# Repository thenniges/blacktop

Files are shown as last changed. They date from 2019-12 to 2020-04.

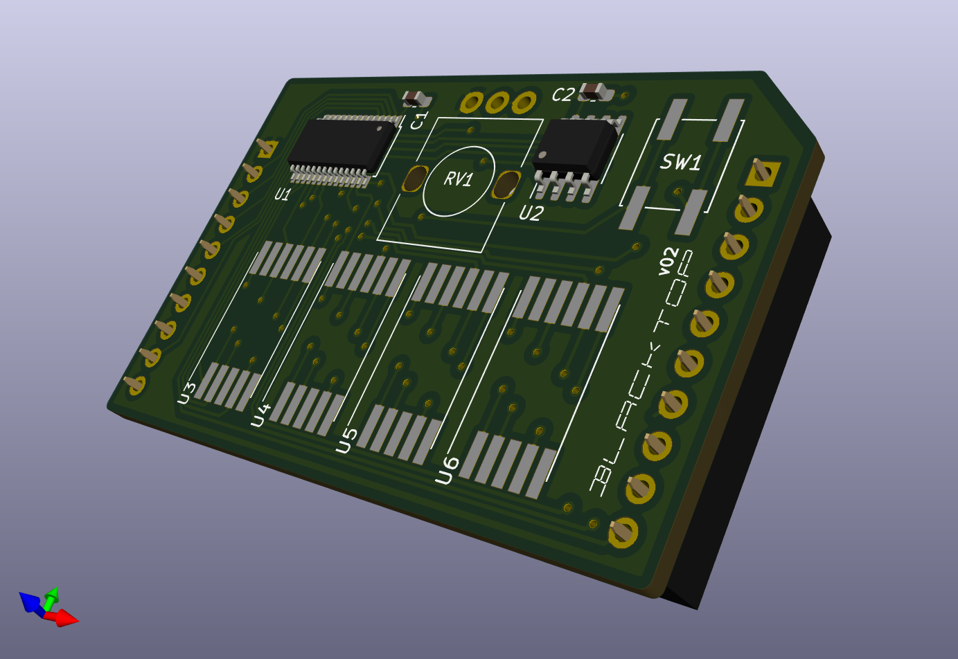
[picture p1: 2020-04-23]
hw/v02/blacktop02.png

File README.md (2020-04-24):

# Blacktop
When cloning this project you need to make some additional git commands to get the unity unit test framework and cmock mock framework

cd blacktop

git submodule init

git submodule update

# Test scripts

There is a test script in the blacktop directory that will run unit tests every time that you save any of the source code. It will run all the unit tests for all subdirectories.

In order to use it you need to install a python tool called when-changed. The command is:

pip install when-changed

Run it in the blacktop directory using the following command:

./watchtests.sh

There is also a system test script in the test folder that can be ran using the following command:

./runtest.sh

# Directories

license: contains the relevant license files for this project

standards: contains the coding standards that should be followed for this project

src: contains the source code and appropriate tests for this project

doc: contains the documentation for this project

spikes: contains spikes that have been done to understand how this project will work

hw: contails kicad files defining the hardware design

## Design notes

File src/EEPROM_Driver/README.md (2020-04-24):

This code uses the Serial Peripheral Interface to allow users to initialize, erase, read, and write the EEPROM memory chip.

eeprom.c and eeprom.h contain the interface for the user to be able to interact with the EEPROM without any knowledge of SPI.
It allows them to be able to easily read and write data to the EEPROM off-chip memory device. The functions are explained briefly in eeprom.h

hardwareDriver.c and hardwareDriver.h allow the eeprom driver to interact with the hardware. None of these functions are intended to be used by the user. They are called appropriately from eeprom.c and eeprom.h 

main.c is used as a system test to ensure that the code is working on your board.

The make file is set up to run the code with main.c as the source file and eeprom.c and hardwareDriver.c as additional files. You can take eeprom.c, eeprom.h, hardwareDriver.c, and hardwareDriver.h and use them with other code. You can also take the makefile and change the source line and add any additional files.

to build the code:
$ make

to remove the binaries:
$ make clean

to flash the code:
$ make flash

to erasse the micro:
$ make erase

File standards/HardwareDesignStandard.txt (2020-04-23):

Use KiCAD 5 for board design.

Use the default KiCAD design rules for feature size and separation.

Instructions for board design in KiCAD 5 are found in Contextual Electronics' "Getting To Blinky 5.0" on YouTube:
https://www.youtube.com/playlist?list=PLy2022BX6EspFAKBCgRuEuzapuz_4aJCn

Schematics must pass KiCAD's Electric Rules Check (ERC) with no errors or warnings.

Layouts must pass KiCAD's Design Rules Check (DRC) with no errors or warnings.

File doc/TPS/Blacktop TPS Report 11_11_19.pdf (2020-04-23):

CS 4900
Project: Blacktop
TPS Report
11/11//2019
Team: | Skyler Sheler | skyler.j.sheler@wmich.edu | (616) 438-3527
| Erron Johnson | erron.d.johnson@wmich.edu | (269) 547-8933
| Allin Kahrl | f.allin.kahrl@wmich.edu | (207) 522-4859
| Tyler Henniges | tyler.m.henniges@wmich.edu | (269) 330-4229
Client: | WMU Computer Club colin.c.maccreery@wmich.edu | (269) 276-3106
Contact: | Colin MacCreery | colin.c.maccreery@wmich.edu | (269) 276-3106
Project Lead Allin Kahrl | f.allin.kahrl@wmich.edu | (207) 522-4859
Task | Who will complete | Time | Risk 1-10 | % complete | Actual time | review
T1 | SS | 1 hour | 1 | 100% | 1 hour | AK TH EJ
T2 | SS AK TH EJ | 1 hour or less | 1 | 75% | TBD | TBD
T3 | SS AK TH EJ | 1 hour | 1 | 100% | 1 hour | AK SS TH EJ
T4 | SS AK TH EJ | 10 hours | 4 | 30% | TBD | TBD
T5 | SS AK TH EJ | 10 hours | 7 | 20% | TBD | TBD
T6 | SS AK TH EJ | 10 hours | 8 | 20% | TBD | TBD

T1: Write the requested deliverables for the week
Write the TPS Report and Stories for the week
T2: Install the toolchain for the MSP 430.
The toolchain necessary to use the board will have to be installed before any circuit prototypes can be tested.
T3: Decide on a licence for the project.

Licencing has yet to be decided upon. This will have to be discussed with the client at our next meeting.

T4: Begin breadboarding a prototype board.
The components will have to be socketed into a breadboard and tested for full functionality. This is currently the largest portion of the project to overcome and time specifications will have to be further analyzed.
T5: Develope drivers using SPI to interface with the on-board EEPROM
Drivers must be developed using a serial peripheral interface to transfer data from the main board to the on-board EEPROM
T6: Develop the CAD files for the production circuit board
The circuit board must be designed via KiCAD before a prototype board can be ordered

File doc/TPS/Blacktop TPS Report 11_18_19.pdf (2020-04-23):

CS 4900
Project: Blacktop
TPS Report
11/18//2019
Team: | Skyler Sheler | skyler.j.sheler@wmich.edu | (616) 438-3527
| Erron Johnson | erron.d.johnson@wmich.edu | (269) 547-8933
| Allin Kahrl | f.allin.kahrl@wmich.edu | (207) 522-4859
| Tyler Henniges | tyler.m.henniges@wmich.edu | (269) 330-4229
Client: | WMU Computer Club colin.c.maccreery@wmich.edu | (269) 276-3106
Contact: | Colin MacCreery | colin.c.maccreery@wmich.edu | (269) 276-3106
Project Lead Allin Kahrl | f.allin.kahrl@wmich.edu | (207) 522-4859
Task | Who will complete | Time | Risk 1-10 | % complete | Actual time | review
T1 | SS | 1 hour | 1 | 100% | 1 hour | AK TH EJ
T2 | SS AK TH EJ | 1 hour or less | 1 | 100% | 1 hour | AK SS TH
T3 | SS AK TH EJ | 5 hours | 3 | 20% | TBD | TBD
T4 | SS AK TH EJ | 10 hours | 3 | 50% | TBD | TBD
T5 | SS AK TH EJ | 10 hours | 6 | 30% | TBD | TBD
T6 | SS AK TH EJ | 10 hours | 6 | 30% | TBD | TBD

T1: Write the requested deliverables for the week
Write the TPS Report and Stories for the week
T2: Install the toolchain for the MSP 430.

The toolchain necessary to use the board will have to be installed before any circuit prototypes can be tested.
T3: Test the board to see if it can handle all of the peripherals being turned on at once
The maximum current load of the board must be determined, and if turning on all peripherals exceeds that load a failsafe must be developed to prevent the board from breaking.
T4: Begin breadboarding a prototype board.
The components will have to be socketed into a breadboard and tested for full functionality. This is currently the largest portion of the project to overcome and time specifications will have to be further analyzed.
T5: Develop drivers using SPI to interface with the on-board EEPROM
Drivers must be developed using a serial peripheral interface to transfer data from the main board to the on-board EEPROM
T6: Develop the CAD files for the production circuit board
The circuit board must be designed via KiCAD before a prototype board can be ordered

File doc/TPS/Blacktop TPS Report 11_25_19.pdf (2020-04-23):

CS 4900
Project: Blacktop
TPS Report
11/25//2019
Team: | Skyler Sheler | skyler.j.sheler@wmich.edu | (616) 438-3527
| Erron Johnson | erron.d.johnson@wmich.edu | (269) 547-8933
| Allin Kahrl | f.allin.kahrl@wmich.edu | (207) 522-4859
| Tyler Henniges | tyler.m.henniges@wmich.edu | (269) 330-4229
Client: | WMU Computer Club colin.c.maccreery@wmich.edu | (269) 276-3106
Contact: | Colin MacCreery | colin.c.maccreery@wmich.edu | (269) 276-3106
Project Lead Allin Kahrl | f.allin.kahrl@wmich.edu | (207) 522-4859
Task | Who will complete | Time | Risk 1-10 | % complete | Actual time | review
T1 | SS | 1 hour | 1 | 100% | 1 hour | AK TH EJ
T2 | SS | 1 hour | 1 | 100% | 1 hour | AK TH EJ
T3 | SS AK TH EJ | 5 hours | 3 | 40% | TBD | TBD
T4 | SS AK TH EJ | 10 hours | 3 | 60% | TBD | TBD
T5 | SS AK TH EJ | 10 hours | 6 | 30% | TBD | TBD
T6 | SS AK TH EJ | 10 hours | 5 | 40% | TBD | TBD
T7 | SS | 3 hours | 1 | 100% | 3 hours | AK
T8 | TH | 1 hour | 1 | 100% | 1 hour | SS AK EJ

T1: Write the requested deliverables for the week
Write the TPS Report and Stories for the week
T2: Test a program on the TSOP MSP-430 chip

The chips soldered to breakout boards must be tested and flashable using the methods used by students in CS2230. Test code was provided to make sure the program operates and performs to the specified standards. Three prototype MSP-430 chips were connected to the programmer via breadboard and tested using a text to ascii code conversion program used in CS2230. The program ran successfully with no errors. The boards were also flashed with a .elf file that causes the on-board rgb to pulse slowly. The program flashed and ran with no errors.
T3: Test the board to see if it can handle all of the peripherals being turned on at once
The maximum current load of the board must be determined, and if turning on all peripherals exceeds that load a failsafe must be developed to prevent the board from breaking.
T4: Finish breadboarding a prototype board.
The components will have to be socketed into a breadboard and tested for full functionality. This is currently the largest portion of the project to overcome and time specifications will have to be further analyzed.
T5: Develop drivers using SPI to interface with the on-board EEPROM
Drivers must be developed using a serial peripheral interface to transfer data from the main board to the on-board EEPROM
T6: Develop the CAD files for the production circuit board
The circuit board must be designed via KiCAD before a prototype board can be ordered T7: Solder together more TSOP MSP-430 programmable chips
Two more TSOP packages were soldered together in case any hardware errors occurred from hand soldering the chips to their respective breakout boards. Allin Kahrl experienced difficulties in getting the package to flash properly so additional boards were made and tested for him to use while the board he used was repaired,
T8: Create a gantt chart to simplify scheduling.
A gantt chart was created to promote steady workflow and establish a well defined timeline for the project.

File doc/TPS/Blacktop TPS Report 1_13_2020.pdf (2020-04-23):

CS 4910
Project: Blacktop
TPS Report
1/13/2020
Team: | Skyler Sheler | skyler.j.sheler@wmich.edu | (616) 438-3527
| Erron Johnson | erron.d.johnson@wmich.edu | (269) 547-8933
| Allin Kahrl | f.allin.kahrl@wmich.edu | (207) 522-4859
| Tyler Henniges | tyler.m.henniges@wmich.edu | (269) 330-4229
Client: | WMU Computer Club colin.c.maccreery@wmich.edu | (269) 276-3106
Contact: | Colin MacCreery | colin.c.maccreery@wmich.edu | (269) 276-3106
Project Lead Allin Kahrl | f.allin.kahrl@wmich.edu | (207) 522-4859
Task | Who will complete | Time | Risk 1-10 | % complete | Actual time | review
T1 | SS | 1 hour | 1 | 100% | 1 hour | AK TH EJ
T2 | SS AK TH EJ | 5 hours | 3 | 50% | TBD | TBD
T3 | SS AK TH EJ | 10 hours | 3 | 80% | TBD | TBD
T4 | SS AK TH EJ | 10 hours | 6 | 70% | TBD | TBD
T5 | SS AK TH EJ | 10 hours | 5 | 50% | TBD | TBD
T6 | AK TH | 5 hours | 1 | 100% | 5 hours | TBD
T1: Write the requested deliverables for the week
Write the TPS Report and Stories for the week
T2: Test the board to see if it can handle all of the peripherals being turned on at once
The maximum current load of the board must be determined, and if turning on all peripherals exceeds that load a failsafe must be developed to prevent the board from breaking.
T3: Finish breadboarding a prototype board.

The components will have to be socketed into a breadboard and tested for full functionality. This is currently the largest portion of the project to overcome and time specifications will have to be further analyzed.
T4: Develop drivers using SPI to interface with the on-board EEPROM
Drivers must be developed using a serial peripheral interface to transfer data from the main board to the on-board EEPROM
T5: Develop the CAD files for the production circuit board
The circuit board must be designed via KiCAD before a prototype board can be ordered T6: Develop a testing plan for the project.
A testing plan for accessibility, user, unit, and system testing must be developed to confirm the projects completeness.

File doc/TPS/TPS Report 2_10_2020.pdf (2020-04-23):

CS 4910
Project: Blacktop
TPS Report
2/10/2020
Team: | Skyler Sheler | skyler.j.sheler@wmich.edu | (616) 438-3527
| Erron Johnson | erron.d.johnson@wmich.edu | (269) 547-8933
| Allin Kahrl | f.allin.kahrl@wmich.edu | (207) 522-4859
| Tyler Henniges | tyler.m.henniges@wmich.edu | (269) 330-4229
Client: | WMU Computer Club colin.c.maccreery@wmich.edu | (269) 276-3106
Contact: | Colin MacCreery | colin.c.maccreery@wmich.edu | (269) 276-3106
Project Lead Allin Kahrl | f.allin.kahrl@wmich.edu | (207) 522-4859
Task | Who will complete | Time | Risk 1-10 | % complete | Actual time | review
T1 | SS | 1 hour | 1 | 100% | 1 hour | AK TH EJ
T2 | SS AK TH EJ | 5 hours | 3 | 100% | TBD | TBD
T3 | SS AK TH EJ | 10 hours | 3 | 80% | TBD | TBD
T4 | SS AK TH EJ | 10 hours | 6 | 75% | TBD | TBD
T5 | AK | 5 hours | 4 | 25% | TBD | TBD
T6 | SS | 10 hours | 5 | 0% | TBD | TBD
T7 | SS TH | 1 hour | 1 | 100% | 1 hour | AK EJ
T8 | TH | 1 hour | 1 | 100% | 1 hour | SS AK EJ
T9 | SS AK | 5 hours | 1 | 50% | TBD | TBD
T10 | TH | 1 hour | 1 | 100% | 1 hour | SS AK EJ
T11 | AK | 1 hour | 1 | 100% | 1 hour | SS TH EJ

T1: Write the requested deliverables for the week
Write the TPS Report and Stories for the week
T2: Test the board to see if it can handle all of the peripherals being turned on at once
The maximum current load of the board must be determined, and if turning on all peripherals exceeds that load a failsafe must be developed to prevent the board from breaking.
T3: Finish breadboarding a prototype board.
The components will have to be socketed into a breadboard and tested for full functionality. This is currently the largest portion of the project to overcome and time specifications will have to be further analyzed.
T4: Develop drivers using SPI to interface with the on-board EEPROM
Drivers must be developed using a serial peripheral interface to transfer data from the main board to the on-board EEPROM
T5: Create revision 3 boards after testing the revision 1 and 2 boards.
T6: Begin Soldering the revision 1 and 2 boards.
T7: Begin research into circuit python for the test jig and its development.
T8: Rework the gantt chart to reflect the current list of completed tasks.
T9: Refine the preliminary powerpoint presentation to reflect desired improvements listed by the class
T10: Decide on an array of possible circuit boards to use for the test jig
T11: Inspect the printed circuit boards that have been ordered and decide on which one to use for first and second stage prototyping

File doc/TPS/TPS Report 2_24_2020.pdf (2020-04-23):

CS 4910
Project: Blacktop
TPS Report
2/24/2020
Team: | Skyler Sheler | skyler.j.sheler@wmich.edu | (616) 438-3527
| Erron Johnson | erron.d.johnson@wmich.edu | (269) 547-8933
| Allin Kahrl | f.allin.kahrl@wmich.edu | (207) 522-4859
| Tyler Henniges | tyler.m.henniges@wmich.edu | (269) 330-4229
Client: | WMU Computer Club colin.c.maccreery@wmich.edu | (269) 276-3106
Contact: | Colin MacCreery | colin.c.maccreery@wmich.edu | (269) 276-3106
Project Lead Allin Kahrl | f.allin.kahrl@wmich.edu | (207) 522-4859
Task | Who will complete | Time | Risk 1-10 | % complete | Actual time | review
T1 | SS | 1 hour | 1 | 100% | 1 hour | AK TH EJ
T2 | SS AK TH EJ | 5 hours | 3 | 100% | 20 hours | AK TH EJ
T3 | SS AK TH EJ | 10 hours | 3 | 100% | TBD | TBD
T4 | SS AK TH EJ | 10 hours | 6 | 75% | TBD | TBD
T5 | AK | 5 hours | 4 | 25% | TBD | TBD
T6 | SS | 10 hours | 5 | 100% | 10 hours | AK EJ TH
T7 | SS AK | 5 hours | 1 | 60% | TBD | TBD
T8 | EJ TH | 1 hour | 1 | 100% | 1 hour | SS AK
T9 | EJ TH | 7 hours | 1 | 100% | 7 hours | SS AK
T10 | SS AK | 3 hours | 5 | 50% | TBD | TBD
T11 | TH | 4 hours | 2 | 100% | 4 hours | TBD

T1: Write the requested deliverables for the week
Write the TPS Report and Stories for the week

T2: Test the board to see if it can handle all of the peripherals being turned on at once
The maximum current load of the board must be determined, and if turning on all peripherals exceeds that load a failsafe must be developed to prevent the board from breaking.
T3: Finish breadboarding a prototype board.
The components will have to be socketed into a breadboard and tested for full functionality. This is currently the largest portion of the project to overcome and time specifications will have to be further analyzed.
T4: Develop drivers using SPI to interface with the on-board EEPROM
Drivers must be developed using a serial peripheral interface to transfer data from the main board to the on-board EEPROM
T5: Create revision 3 boards after testing the revision 1 and 2 boards.
T6: Begin Soldering the revision 1 and 2 boards.
Both revision 1 and 2 have been completed, there are minor errors that need to be accounted for.
T7: Refine the preliminary powerpoint presentation to reflect desired improvements listed by the class
T8: Fix revision 1 board
A solder bridge and an error in the traces was found in the rev1 board. This will need to be corrected for rev 3 as it is probably present in rev 2. Bodge wire was used to accomplish this
T9 write a test program for the rev1 board
T10: Probe the current rev1 and rev2 boards for why the potentiometer does not work. T11: Write an additional test program to test the boards.

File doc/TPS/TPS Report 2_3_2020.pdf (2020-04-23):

CS 4910
Project: Blacktop
TPS Report
2/3/2020
Team: | Skyler Sheler | skyler.j.sheler@wmich.edu | (616) 438-3527
| Erron Johnson | erron.d.johnson@wmich.edu | (269) 547-8933
| Allin Kahrl | f.allin.kahrl@wmich.edu | (207) 522-4859
| Tyler Henniges | tyler.m.henniges@wmich.edu | (269) 330-4229
Client: | WMU Computer Club colin.c.maccreery@wmich.edu | (269) 276-3106
Contact: | Colin MacCreery | colin.c.maccreery@wmich.edu | (269) 276-3106
Project Lead Allin Kahrl | f.allin.kahrl@wmich.edu | (207) 522-4859
Task | Who will complete | Time | Risk 1-10 | % complete | Actual time | review
T1 | SS | 1 hour | 1 | 100% | 1 hour | AK TH EJ
T2 | SS AK TH EJ | 5 hours | 3 | 100% | TBD | TBD
T3 | SS AK TH EJ | 10 hours | 3 | 80% | TBD | TBD
T4 | SS AK TH EJ | 10 hours | 6 | 75% | TBD | TBD
T5 | SS AK TH EJ | 10 hours | 5 | 100% | 10 hours | SS EJ TH
T6 | AK TH | 5 hours | 1 | 100% | 5 hours | SS EJ
T7 | AK | 3 hours | 3 | 100% | 3 hours | SS EJ TH
T8 | AK | 1 hour | 1 | 100% | 1 hour | SS EJ TH
T9 | AK | 1 hour | 1 | 100% | 1 hour | SS EJ TH

T10 | AK | 1 hour | 1 | 100% | 1 hour | SS EJ TH
T11 | SS | 1 hour | 1 | 100% | 1 hour | AK EJ TH

T1: Write the requested deliverables for the week
Write the TPS Report and Stories for the week
T2: Test the board to see if it can handle all of the peripherals being turned on at once
The maximum current load of the board must be determined, and if turning on all peripherals exceeds that load a failsafe must be developed to prevent the board from breaking.
T3: Finish breadboarding a prototype board.
The components will have to be socketed into a breadboard and tested for full functionality. This is currently the largest portion of the project to overcome and time specifications will have to be further analyzed.
T4: Develop drivers using SPI to interface with the on-board EEPROM
Drivers must be developed using a serial peripheral interface to transfer data from the main board to the on-board EEPROM
T5: Develop the CAD files for the production circuit board
The circuit board must be designed via KiCAD before a prototype board can be ordered T6: Develop a testing plan for the project.
A testing plan for accessibility, user, unit, and system testing must be developed to confirm the projects completeness.
T7: Develop improved kicad files for revision 2 of the prototype board
Allin Kahrl has begun and continued development on an improved board schematic based on conventions used in professional CAD development that will improve the overall board layout
T8: Order the revision 1 boards
T9: Order the revision 2 boards
T10: Order surface mount components
T11: Research hand soldering techniques for the surface mount components
Since several components use pads rather than pins another approach will need to be taken to adhere the components to the board.

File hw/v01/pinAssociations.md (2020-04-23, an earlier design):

CHIP	BOARD	FUNCTION
2	P1.0	P1.0 = GREEN LED
3	P1.1	P1.1 = UART RECEIVE
4	P1.2	P1.2 = UART TRANSMIT
5	P1.3	P1.3 = ONBOARD BUTTON
6		P1.4 = POTENTIOMETER INPUT
7		P1.5 = EEPROM CLOCK
22		P1.6 = EEPROM SOMI
23		P1.7 = EEPROM SIMO
10		P2.0 = SEGMENT A
11		P2.1 = SEGMENT B
12		P2.2 = SEGMENT C
16		P2.3 = SEGMENT D
17		P2.4 = SEGMENT E
18		P2.5 = SEGMENT F
27		P2.6 = SEGMENT G (XIN)
26		P2.7 = EXTRA BUTTON (XOUT)
9		P3.0 = DIGIT 1
8		P3.1 = DIGIT 2
13	P2.3	P3.2 = ONBOARD RGB (GREEN) TA1.1
14	P2.1	P3.3 = ONBOARD RGB (BLUE) TA1.2
15		P3.4 = DIGIT 3
19	P2.5	P3.5 = ONBOARD RGB (RED) TA0.1
20	P1.6	P3.6 = ONBOARD RED
21		P3.7 = DIGIT 4

24	~RST
25	TEST	

1	3V3
28	GND

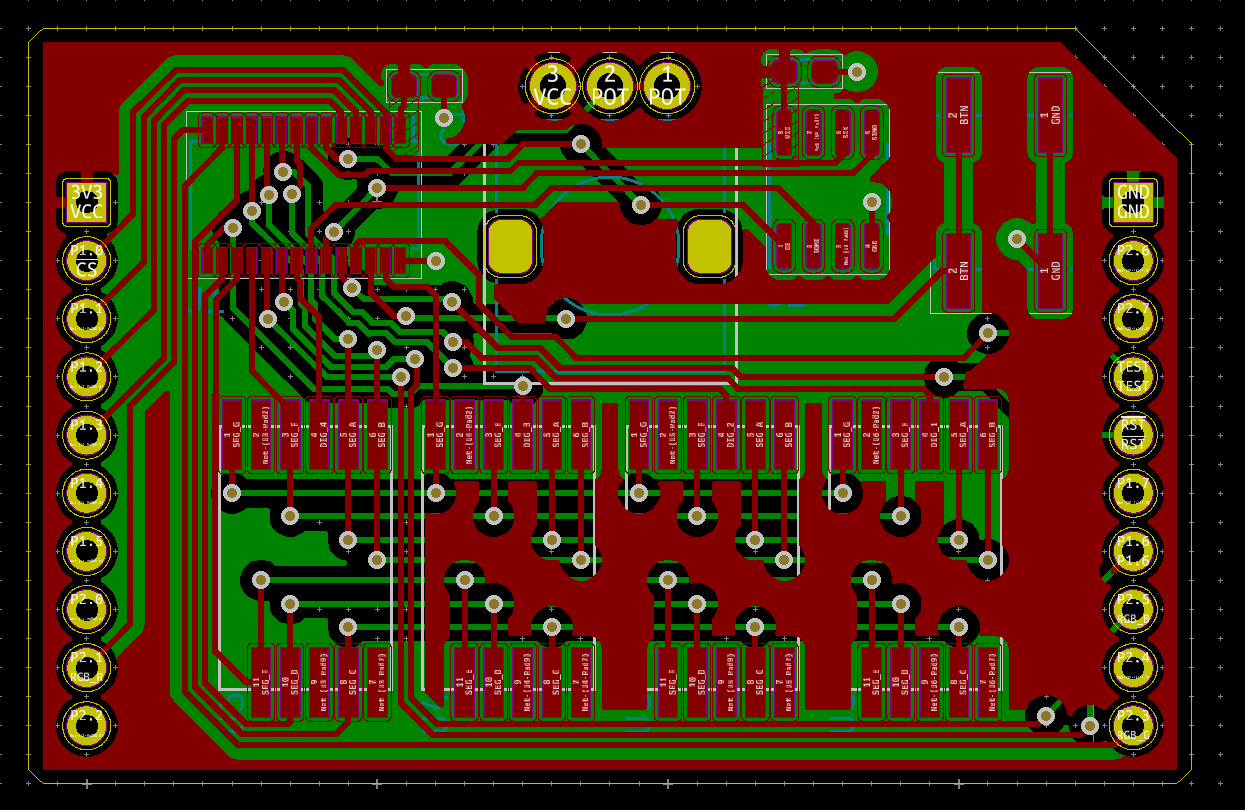
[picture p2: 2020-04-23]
hw/v02/Screenshot from 2020-01-30 21-04-03.png

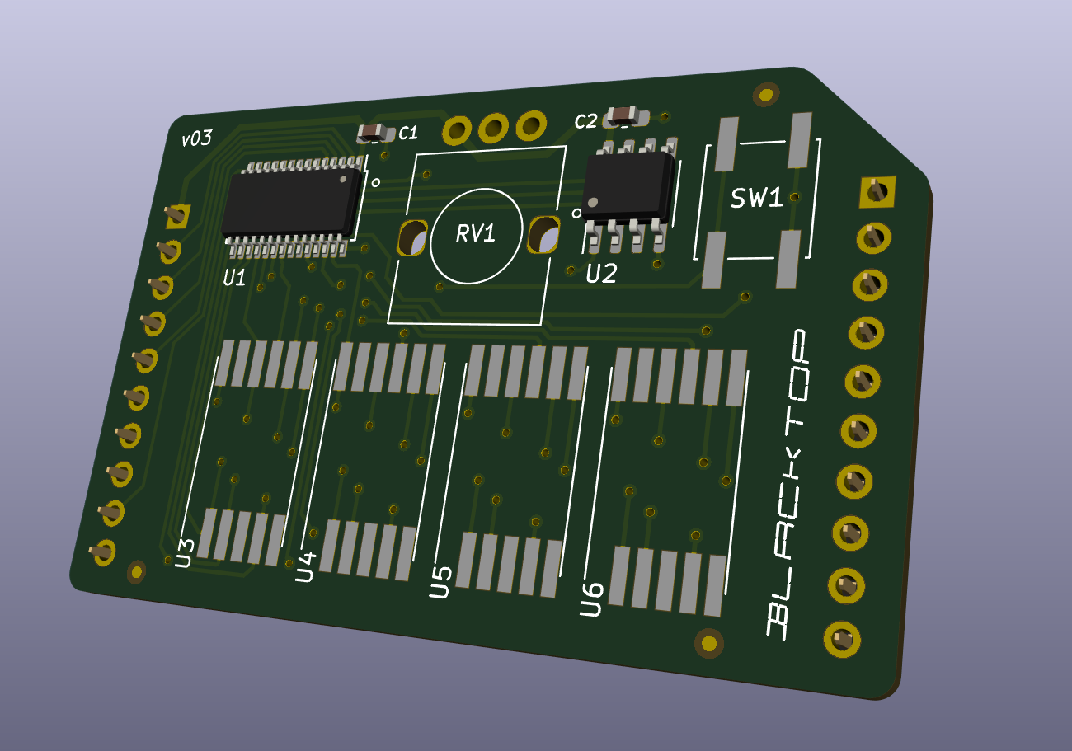
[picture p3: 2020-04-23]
hw/v02/blacktop03.png

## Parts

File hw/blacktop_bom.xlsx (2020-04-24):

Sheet: 2020-03-02
Make | Item | Description | Source | Qty | $/unit @ 100+ | Unit Total
TI | MSP430G2553IPW28R | Microcontroller w/ 3 8-bit GPIO ports, TSSOP-28 | Mouser/DK | 1 | $1.67 | $1.67
Broadcom | HDSM-283L | 7-seg digit, 7mm orange, common cathode, SMD | Mouser/DK | 4 | $1.30 | $5.20
Panasonic | EVQ-Q2Y03W | momentary button, SMD | SBA | 1 | $0.25 | $0.25
Microchip | AT25640B-SSHL-T | 64kbit SPI EEPROM, SOIC-8 | Mouser/DK | 1 | $0.42 | $0.42
Murata |  | CAP CER 0.1UF 25V 10% X7R 0603 | SBA | 2 | $0.28 | $0.56
Bourns | PTV09A-4015U-B103 | 10k pot, top 6mm shaft, through-hole | Mouser/DK | 1 | $0.62 | $0.62
Samtech | CES-110-01-G-S | Headers .100" Closed Entry Low Profile Socket Strip | Mouser/DK | 2 | $1.72 | $3.44
PCB |  |  | OSHPark | 2.6 | $1.00 | $2.60
assembly |  |  | SBA | 1 | $3.65 | $3.65
 |  |  |  |  |  | $18.42

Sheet: 2020-02-07
Make | Item | Description | Source | Qty | $/unit @ 100+ | Unit Total
TI | MSP430G2553IPW28R | Microcontroller w/ 3 8-bit GPIO ports, TSSOP-28 | Mouser/DK | 1 | $1.67 | $1.67
Broadcom | HDSM-283L | 7-seg digit, 7mm orange, common cathode, SMD | Mouser/DK | 4 | $1.30 | $5.20
Panasonic | EVQ-Q2Y03W | momentary button, SMD | SBA | 1 | $0.25 | $0.25
Microchip | AT25640B-SSHL-T | 64kbit SPI EEPROM, SOIC-8 | Mouser/DK | 1 | $0.42 | $0.42
Murata |  | CAP CER 0.1UF 25V 10% X7R 0603 | SBA | 2 | $0.28 | $0.56
Bourns | PTV09A-4015U-B103 | 10k pot, top 6mm shaft, through-hole | Mouser/DK | 1 | $0.62 | $0.62
Samtech | CES-110-01-G-S | Headers .100" Closed Entry Low Profile Socket Strip | Mouser/DK | 2 | $1.72 | $3.44
PCB |  |  | OSHPark | 2.6 | $1.00 | $2.60
assembly |  |  | SBA | 1 | $3.65 | $3.65
 |  |  |  |  |  | $18.42

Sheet: 2020-01-22
Make | Item | Description | Source | Qty | $/unit @ 100+ | Unit Total
TI | MSP430G2553IPW28R | Microcontroller w/ 3 8-bit GPIO ports, TSSOP-28 | Mouser/DK | 1 | $1.67 | $1.67
Broadcom | HDSM-283L | 7-seg digit, 7mm orange, common cathode, SMD | Mouser/DK | 4 | $1.30 | $5.20
Panasonic | EVQ-Q2Y03W | momentary button, SMD | SBA | 1 | $0.25 | $0.25
Microchip | AT25640B-SSHL-T | 64kbit SPI EEPROM, SOIC-8 | Mouser/DK | 1 | $0.42 | $0.42
Murata |  | CAP CER 0.1UF 25V 10% X7R 0603 | SBA | 2 | $0.28 | $0.56
Bourns | PTV09A-4020U-B103 | 10k pot, top 6mm shaft, through-hole | Mouser/DK | 1 | $0.62 | $0.62
PCB |  |  | OSHPark | 2.6 | $1.00 | $2.60
assembly |  |  | SBA | 1 | $4.38 | $4.38
 |  |  |  |  |  | $15.71

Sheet: Sheet1
Make | Item | Description | Qty | $/unit @ 100+ | Unit Total
TI | MSP430G2553IRHB32R | Microcontroller w/ 3 8-bit GPIO ports, VQFN pkg. | 1 | $1.68 | $1.68
Broadcom | HDSM-283L | 7-seg digit, 7mm orange, common cathode, SMD | 4 | $1.30 | $5.20
E-Switch | LL3301NF065QG | momentary button, SMD | 2 | $0.61 | $1.22
ALPS | RK14J11R000J | 10k linear pot, side wheel, SMD | 1 | $1.03 | $1.03
DB Unlimited | TP124003-2 | 4kHz 12mm piezo transducer, SMD | 1 | $1.27 | $1.27
Microchip | AT25640B-SSHL-T | 64kbit SPI EEPROM, SOIC-8 | 1 | $0.42 | $0.42
Murata |  | CAP CER 0.1UF 25V 10% X7R 0603 | 2 | $0.28 | $0.56
PCB |  |  | 3.42 | $1.00 | $3.42
assembly |  |  | 1 | $5.42 | $5.42
 |  |  |  |  | $20.22

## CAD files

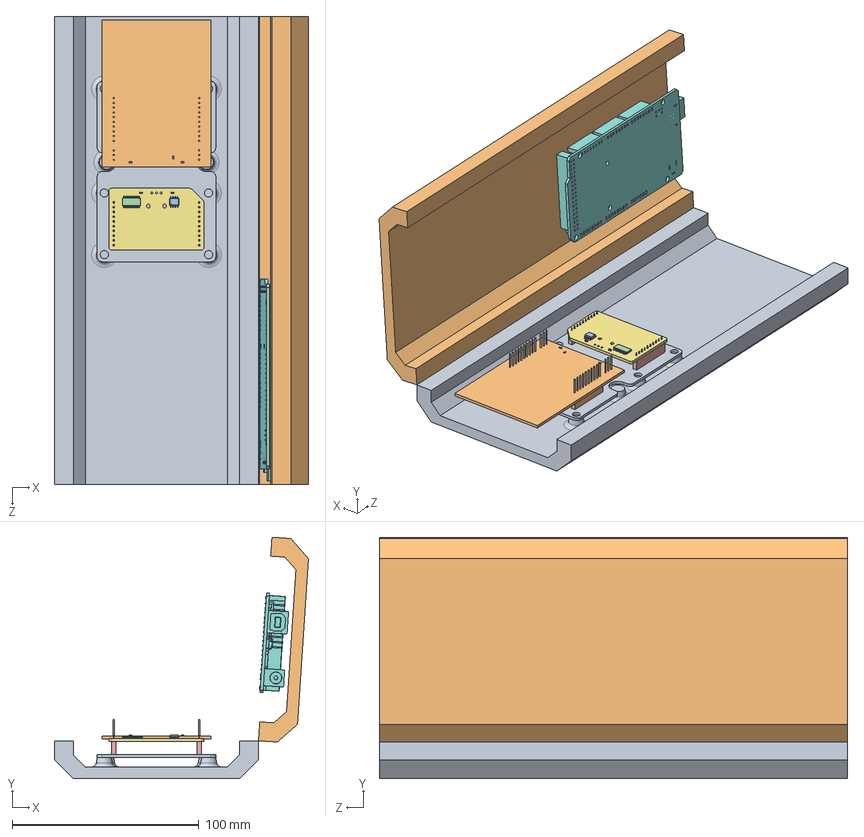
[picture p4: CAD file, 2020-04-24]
hw/jig/blacktopTestJig.SLDASM
136.0 x 129.3 x 250.8 mm
base
MSP-EXP430G2ET
SOLID.step
SOLID-0.step
SOLID-1.step x 2
SOLID-2.step x 2
COMPOUND.step
ArduinoMega
CaseLower
CaseUpper

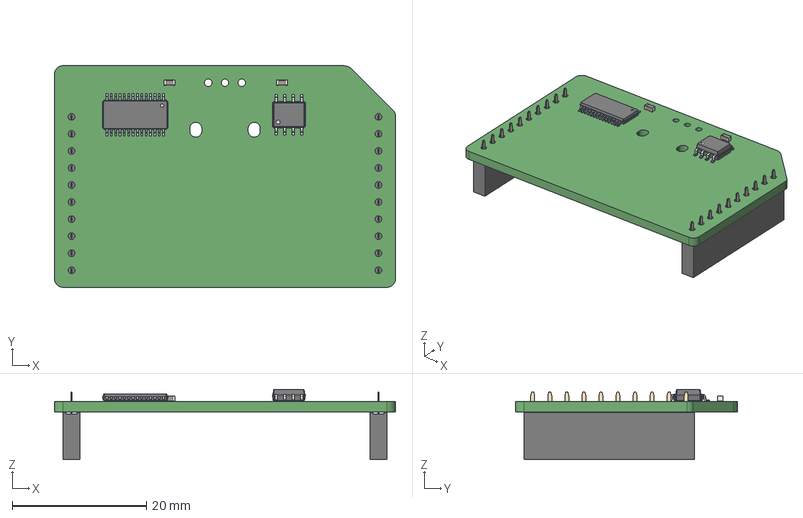
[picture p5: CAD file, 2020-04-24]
hw/v02/blacktop02.step
50.8 x 33.0 x 10.5 mm
SW_SPST_EVQQ2

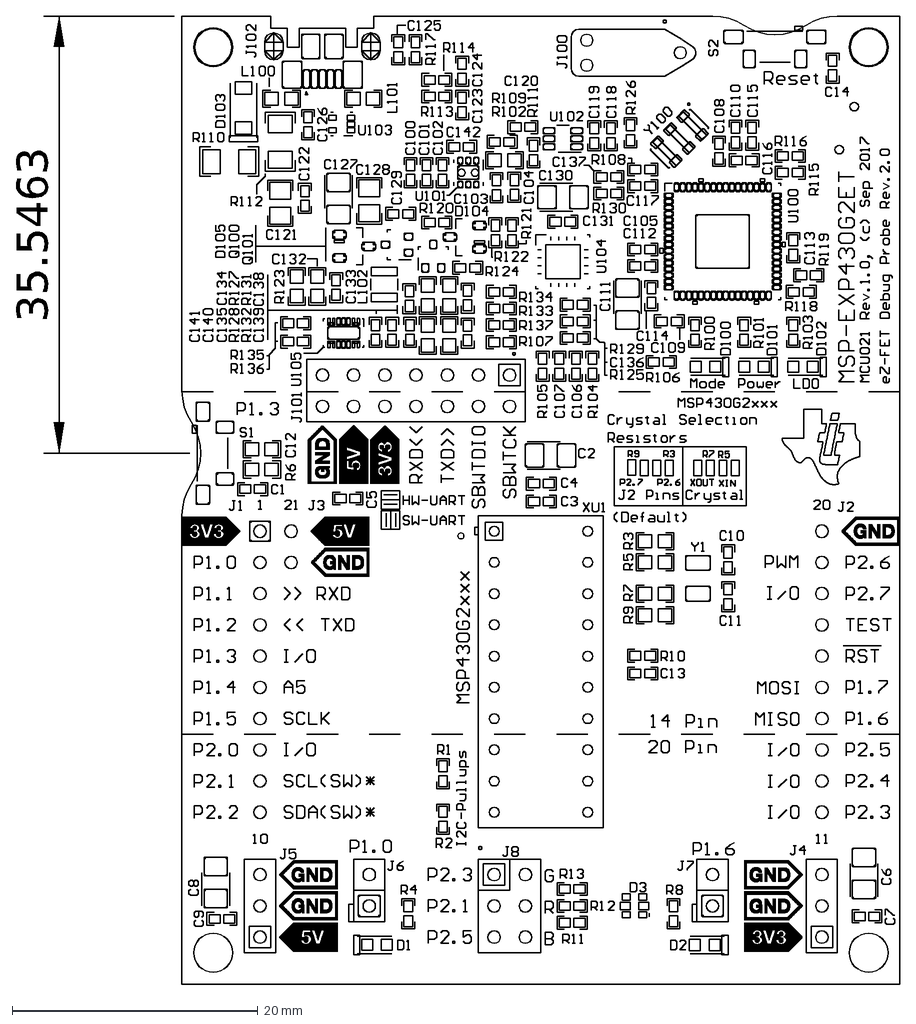
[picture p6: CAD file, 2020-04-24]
hw/jig/#MSP-EXP430G2ET-1.dxf
35.5463

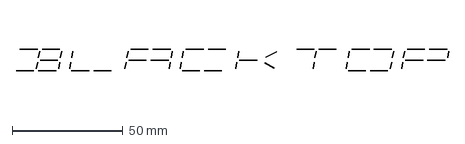
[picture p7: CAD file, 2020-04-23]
hw/v02/16seg_logo_nox.dxf
195.6 x 9.85 mm

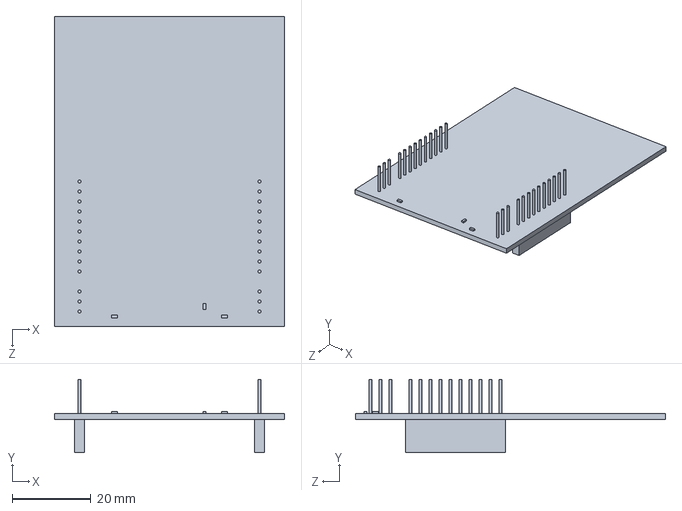
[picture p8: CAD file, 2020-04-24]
hw/jig/MSP-EXP430G2ET.SLDPRT
58.4 x 18.6 x 78.7 mm

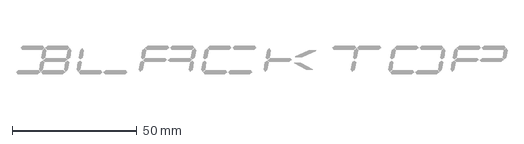
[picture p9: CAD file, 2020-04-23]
hw/v02/16seg_logo_noseg.dxf
197.1 x 11.3 mm

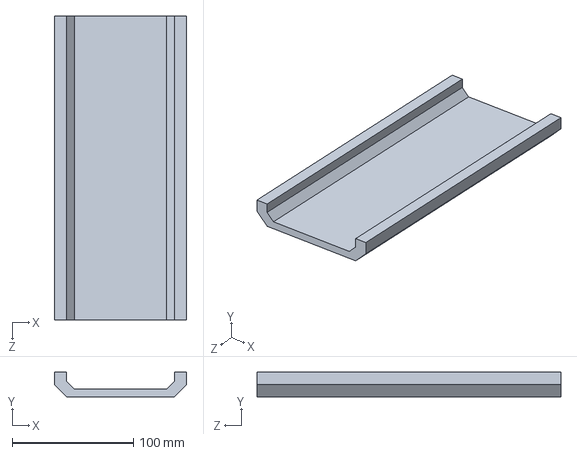
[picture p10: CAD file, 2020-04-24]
hw/jig/CaseUpper.SLDPRT
109.2 x 20.3 x 250.8 mm

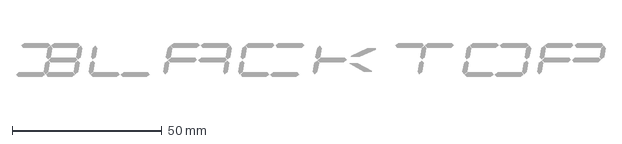
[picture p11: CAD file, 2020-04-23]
hw/v02/16seg_logo.dxf
197.1 x 11.3 mm

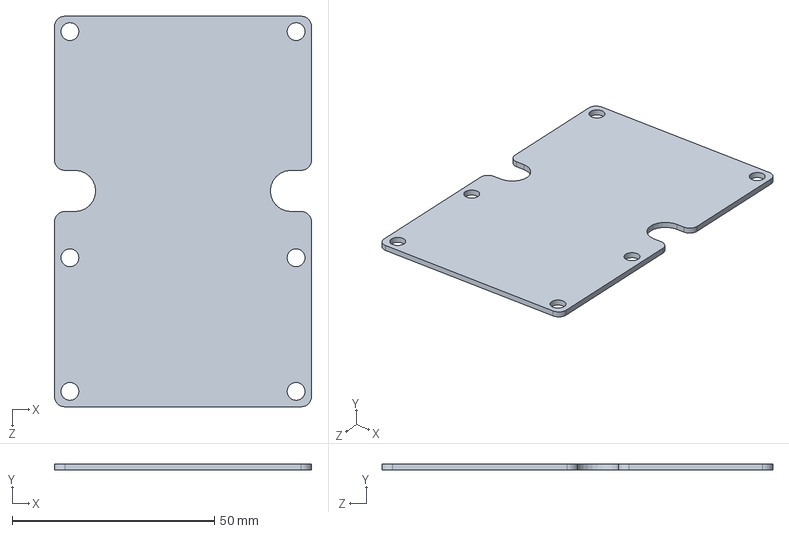
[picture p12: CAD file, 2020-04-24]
hw/jig/base.SLDPRT
63.5 x 1.59 x 96.5 mm

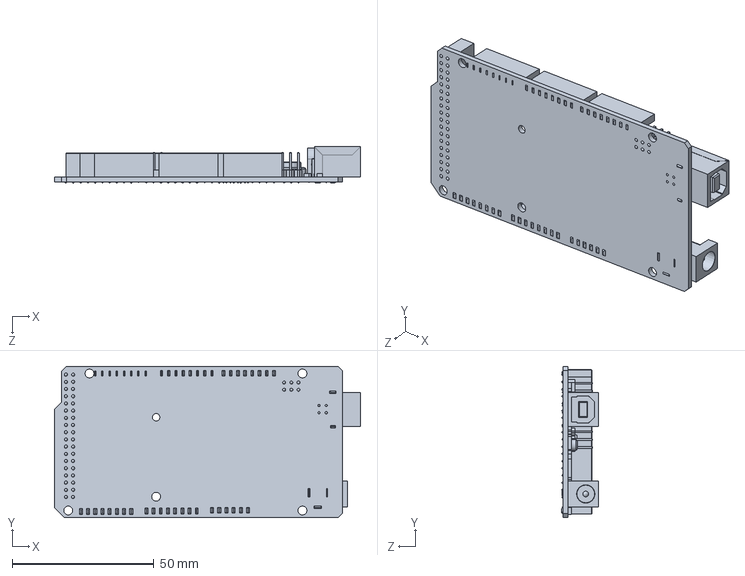
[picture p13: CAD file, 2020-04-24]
hw/jig/ArduinoMega.SLDPRT
107.9 x 53.4 x 13.0 mm

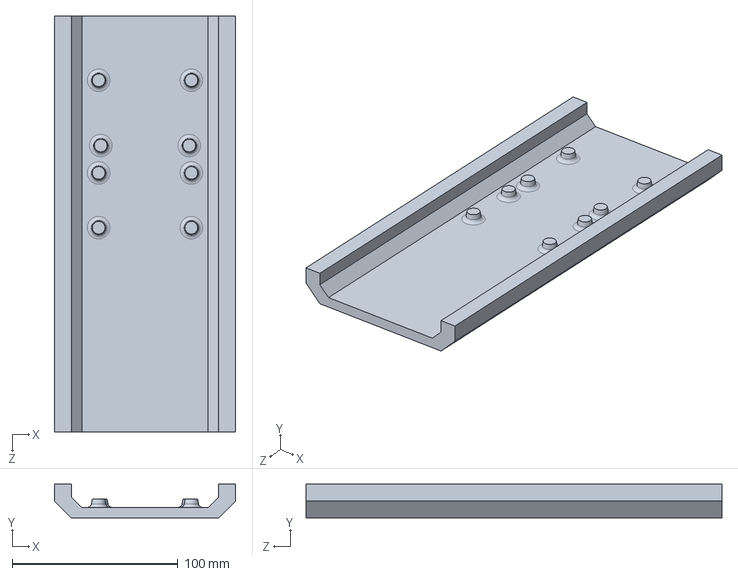
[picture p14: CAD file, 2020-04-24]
hw/jig/CaseLower.SLDPRT
109.2 x 20.3 x 250.8 mm

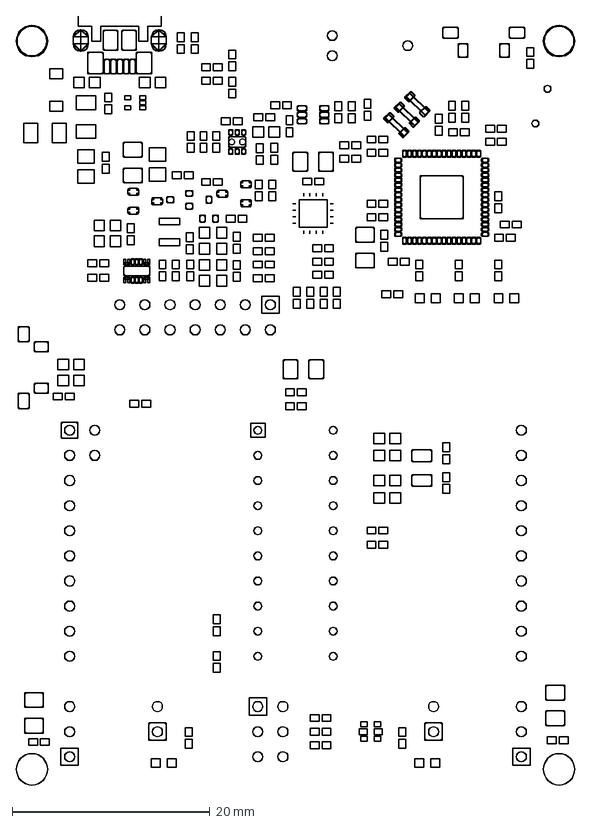
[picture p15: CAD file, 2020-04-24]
hw/jig/#MSP-EXP430G2ET-2.dxf
56.5 x 77.8 mm

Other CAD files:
hw/jig/MSP-EXP430G2ET-1.dxf
hw/jig/MSP-EXP430G2ET-2.dxf

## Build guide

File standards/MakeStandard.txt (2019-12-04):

This document will define our make standard for the blacktop project

There will be one main makefile within the src directory that will build the final executable. There will also be makefiles within each sub-directory of src to create unit testing executables for each module of the project.

You must explicitly specify the make rules, you cannot let them use the default.
You cannot do any strange makefile things, all makefiles should be easy to read.
The only variables that should be used in your makefiles are CC and CFLAGS

Every makefile should define the compiler and the c-flags at the top. The compiler should be defined as gcc and the c-flags should be defined as -Wall -pedantic -std=c11

This is exactly what this should look like:

CC = gcc
CFLAGS = -Wall -pedantic -std=c11

There should be several lines to create the object files. 

This should look like this:

getIt.o: getIt/getIt.c getIt/getIt.h
	${CC} ${CFLAGS} -c getIt/getIt.c

The first line of the makefile will create the main executable.

This should look like this:

quadsolver: quadsolver.o getIt.o putIt.o format.o calculate.o validate.o
	${CC} ${CFLAGS} getIt.o putIt.o format.o calculate.o validate.o quadsolver.o -o quadsolver

Finally, every makefile should have a clean rule. It should remove the executable, the object files, and the core.

This should look like:

clean:
	rm -f *.o core quadsolver

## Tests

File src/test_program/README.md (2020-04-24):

This project uses the pin layout that is the same as the first rev of the PCB
The goal of this spike was to write a simple test program that can test everything except the EEPROM

The program starts by cycling through the hex values 0-F on each digit one by one
When that completes, the onboard red and green leds should be on
The RGB LED should have Red and Green on plus whatever percentage of Blue the potentiometer represents

Pushing the onboard button toggles the onboard red led
Pushing the extra button (on the pcb) toggles the onboard green led
Changing the potentiometer changes the red of the rgb led

to build the code:
$ make

to flash the code:
$ make flash

CHIP    BOARD   FUNCTION

2       P1.0	P1.0 = GREEN LED/EEPROM CS

3	    P1.1	P1.1 = UART RECEIVE

4	    P1.2	P1.2 = UART TRANSMIT

5	    P1.3	P1.3 = ONBOARD BUTTON

6		        P1.4 = POTENTIOMETER INPUT

7		        P1.5 = EEPROM CLOCK

22		        P1.6 = EEPROM SOMI

23		        P1.7 = EEPROM SIMO

10		        P2.0 = SEGMENT A

11		        P2.1 = SEGMENT B

12		        P2.2 = SEGMENT C

16		        P2.3 = SEGMENT D

17		        P2.4 = SEGMENT E

18		        P2.5 = SEGMENT F

27		        P2.6 = SEGMENT G (XIN)

26		        P2.7 = EXTRA BUTTON (XOUT)

9		        P3.0 = DIGIT 1

8		        P3.1 = DIGIT 2

13	    P2.3	P3.2 = ONBOARD RGB (GREEN) TA1.1

14	    P2.1	P3.3 = ONBOARD RGB (BLUE) TA1.2

15		        P3.4 = DIGIT 3

19	    P2.5	P3.5 = ONBOARD RGB (RED) TA0.1

20	    P1.6	P3.6 = ONBOARD RED

21		        P3.7 = DIGIT 4

24	    ~RST

25	    TEST

1	    3V3

28	    GND

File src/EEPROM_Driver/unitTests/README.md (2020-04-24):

This folder contains unit tests for the EEPROM driver. It tests the eeeprom files and mocks the hardwareDriver files. It verifies the messages being created in the EEPRom driver and abstracts out the hardware. This allows the unit tests to run locally on your computer

To run the tests:

$ cmake .
$ make
$ ./eepromTests

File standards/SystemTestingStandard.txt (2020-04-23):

There must be a physical test fixture, capable of holding the hardware being tested, and using sensors to report on any feedback that the MSP430 cannot report to the host computer itself (such as photocells corresponding to LEDs).

There must be a three-piece suite of software to perform automated testing of the hardware:
Code that runs on the host computer and commands the MSP430 via USB serial communication.
Code that is flashed to the MSP430 and responds to commands from the host computer allowing operation of every element of the hardware and reporting back on the results of any tests without visible feedback (such as EEPROM testing).
Code that runs on the test fixture that reports feedback from LEDs to the host computer.

The host computer code must concisely log results during hardware acceptance testing.

Every hardware element must be tested both in isolation, and working in concert with others. For instance, every segment of the 7-segment displays should be tested alone, each 7-segment unit should be run through the hexadecimal digits, and all four units should run through the hexadecimal digits together. Likewise, the EEPROM should be tested both as the only peripheral being accessed by the processor, and along with other devices (within the limitations of the MSP430 interrupt architecture).

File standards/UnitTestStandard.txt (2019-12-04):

We will use Unity for our unit testing framework and cmock for mocking functions.

Unit tests should be written to sufficiently test each function of the code.

Unit tests should run independently of one another meaning that you could change the order and it would not effect their success because they do not depend on the state of the program from other previous tests.

Unit tests should be self validating and should only output upon failure.

Unit tests should cover every use case scenario, especially edge cases. Unit tests should also provide sufficient coverage so that every line of code is tested.

If you are writing code and you break a test, go back and fix that code even if you did not write it. We all share responsibility for the project.

No code should be submitted to the repository if it is not properly tested and passing all the appropriate tests including tests written for other modules by other programmers.

A getting started guide for Unity can be found at https://github.com/ThrowTheSwitch/Unity/blob/master/docs/UnityGettingStartedGuide.md

A getting started guide for cmock can be found at https://github.com/ThrowTheSwitch/CMock/blob/master/docs/CMock_Summary.md

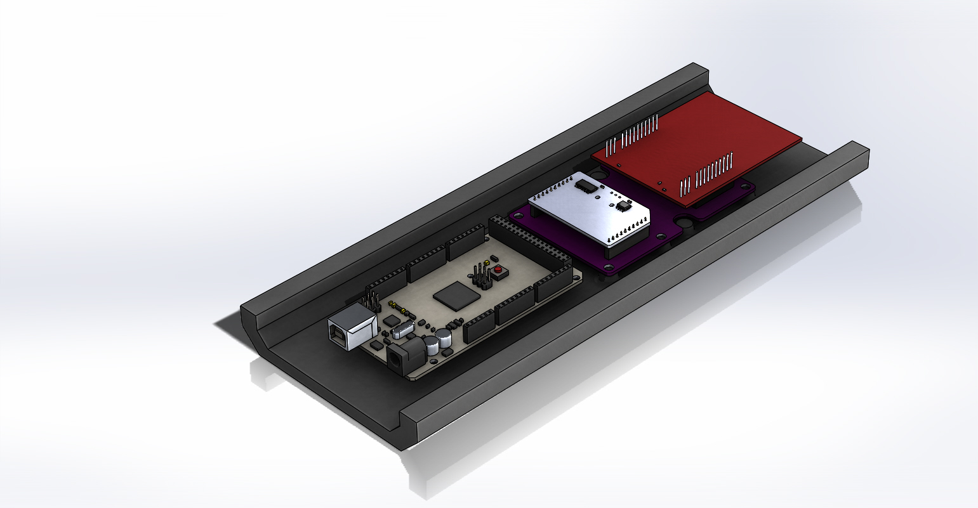
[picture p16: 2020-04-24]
hw/jig/blacktopTestJig.JPG

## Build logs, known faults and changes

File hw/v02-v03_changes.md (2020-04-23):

v03 changes:
============

- move SW1 left as much as possible
- increase size of upper right cutout
- add fiducial marks for p&p
- switch logo to front copper
- add U1 & U2 orientation marks
- replace VCC pour with rail
- ground pot third pin and separate from sweep

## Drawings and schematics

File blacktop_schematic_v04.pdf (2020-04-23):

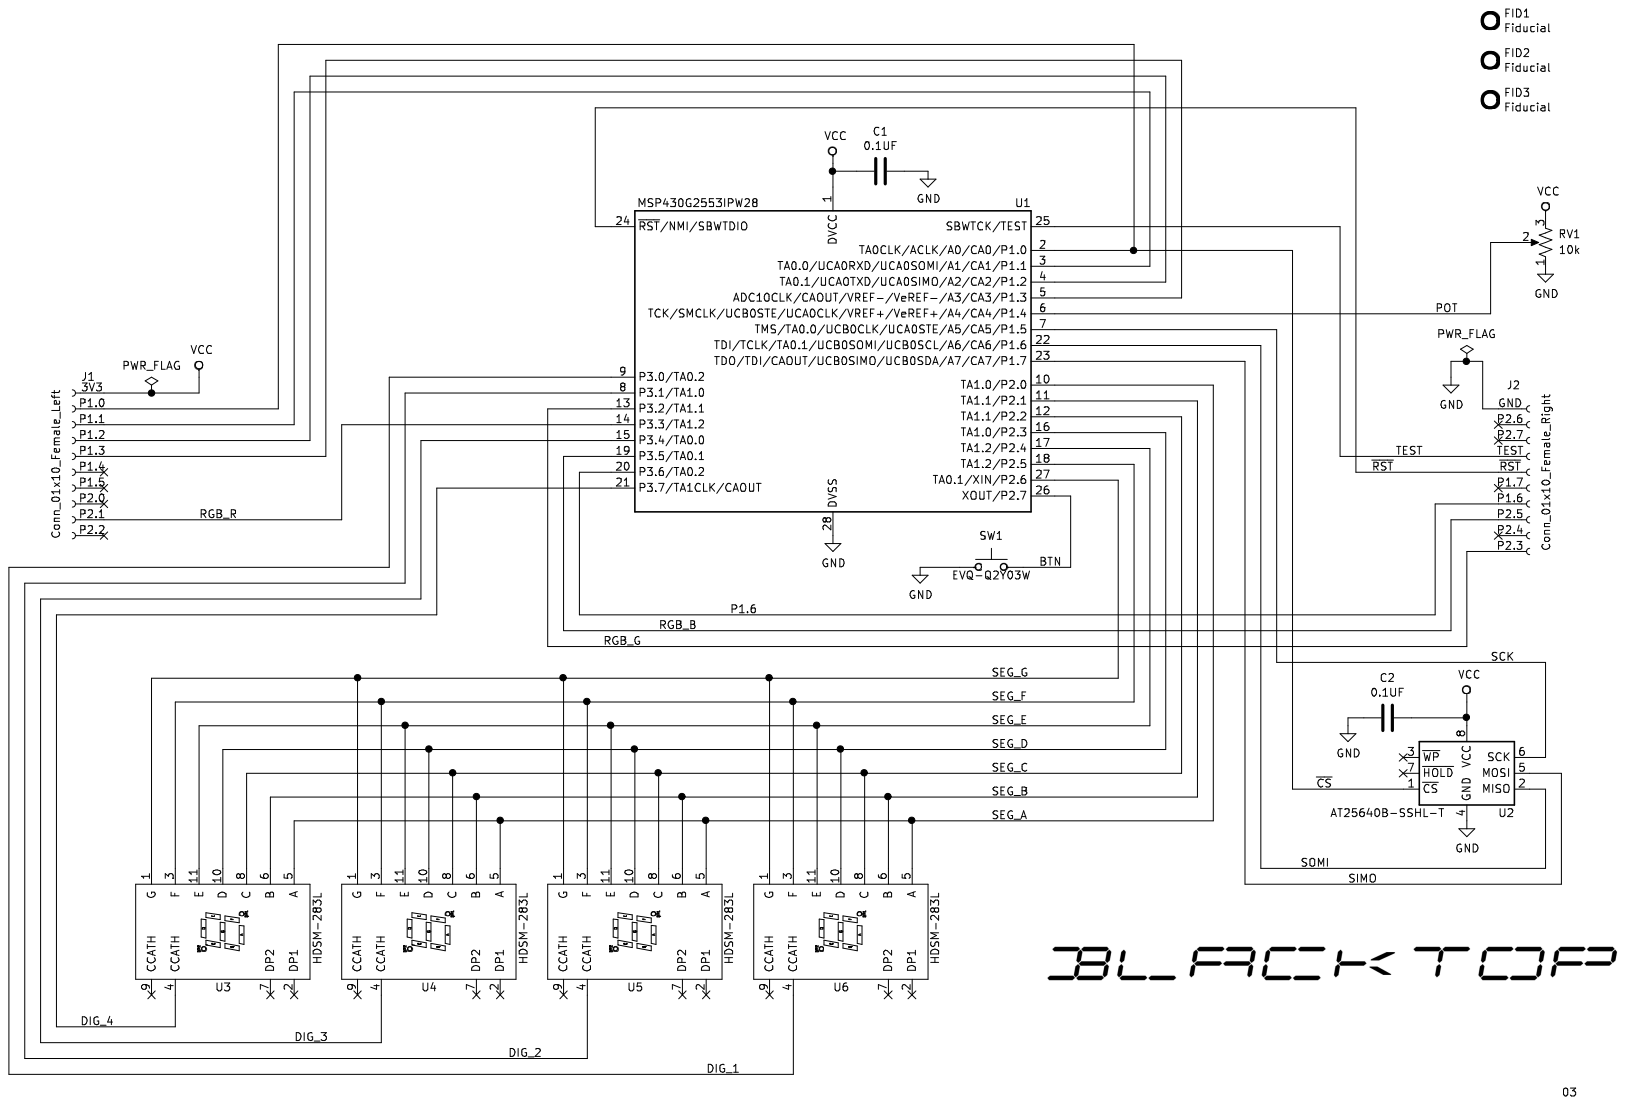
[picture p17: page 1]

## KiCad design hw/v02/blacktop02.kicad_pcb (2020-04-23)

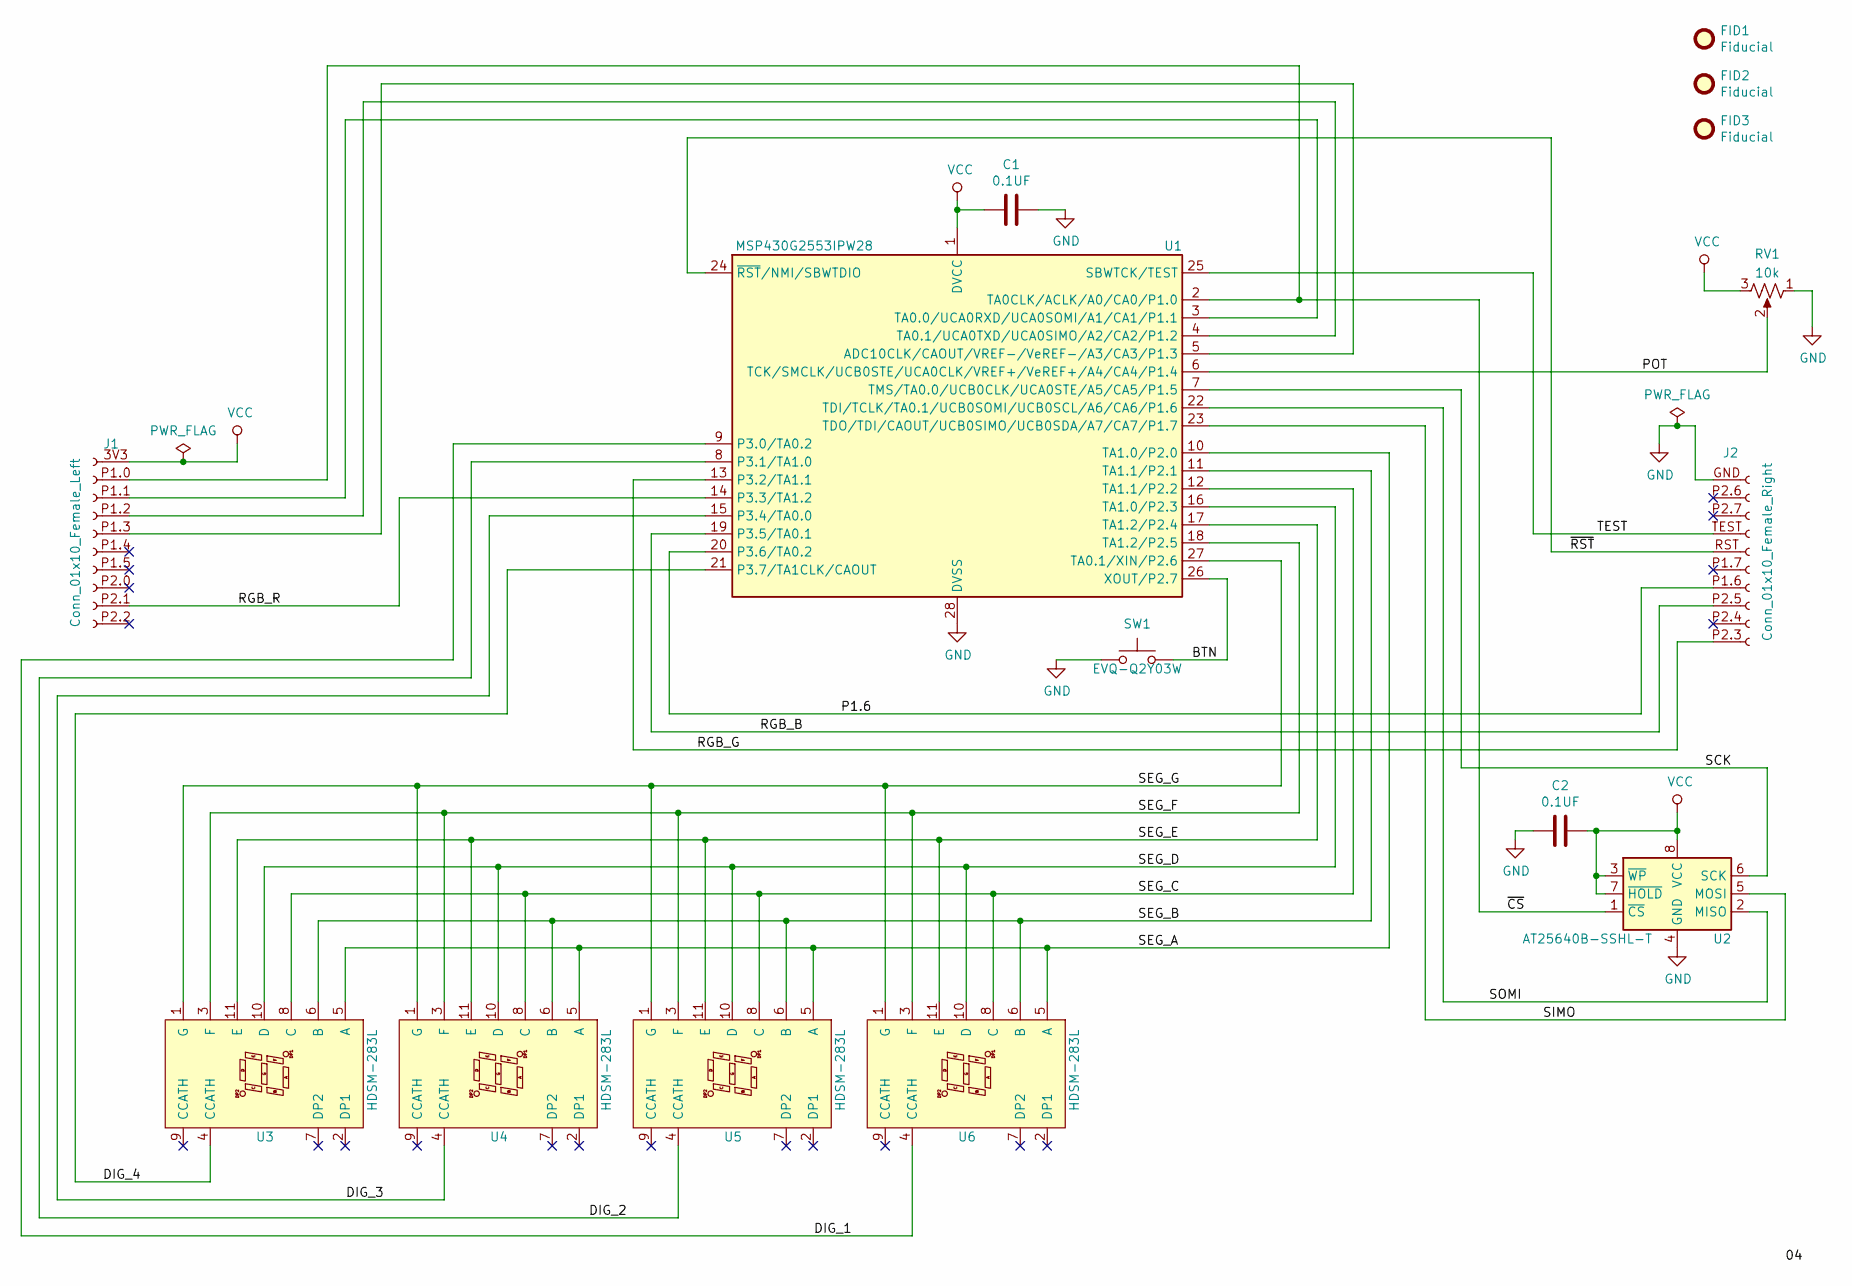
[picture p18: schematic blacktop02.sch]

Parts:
C1, C2: 0.1UF; C_0603_1608Metric_Pad1.05x0.95mm_HandSolder
FID1, FID2, FID3: Fiducial; Fiducial_0.75mm_Mask1.5mm
J1: Conn_01x10_Female_Left; PinSocket_1x10_P2.54mm_Vertical_Left
J2: Conn_01x10_Female_Right; PinSocket_1x10_P2.54mm_Vertical_Right
RV1: 10k; PTV09A-4020U-B103
SW1: EVQ-Q2Y03W; SW_SPST_EVQQ2
U1: MSP430G2553IPW28; TSSOP-28_4.4x9.7mm_P0.65mm
U2: AT25640B-SSHL-T; SOIC-8_3.9x4.9mm_P1.27mm
U3, U4, U5, U6: HDSM-283L

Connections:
/BTN: SW1.2, U1.26 (XOUT/P2.7)
/DIG_1: U1.9 (P3.0/TA0.2), U6.4 (CCATH)
/DIG_2: U1.8 (P3.1/TA1.0), U5.4 (CCATH)
/DIG_3: U1.15 (P3.4/TA0.0), U4.4 (CCATH)
/DIG_4: U1.21 (P3.7/TA1CLK/CAOUT), U3.4 (CCATH)
/P1.6: J2.P1.6 (Pin_14), U1.20 (P3.6/TA0.2)
/POT: RV1.2, U1.6 (TCK/SMCLK/UCB0STE/UCA0CLK/VREF+/VeREF+/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)
/RGB_B: J2.P2.5 (Pin_13), U1.19 (P3.5/TA0.1)
/RGB_G: J2.P2.3 (Pin_11), U1.13 (P3.2/TA1.1)
/RGB_R: J1.P2.1 (Pin_9), U1.14 (P3.3/TA1.2)
/SCK: U1.7 (TMS/TA0.0/UCB0CLK/UCA0STE/A5/CA5/P1.5), U2.6 (SCK)
/SEG_A: U1.10 (TA1.0/P2.0), U3.5 (A), U4.5 (A), U5.5 (A), U6.5 (A)
/SEG_B: U1.11 (TA1.1/P2.1), U3.6 (B), U4.6 (B), U5.6 (B), U6.6 (B)
/SEG_C: U1.12 (TA1.1/P2.2), U3.8 (C), U4.8 (C), U5.8 (C), U6.8 (C)
/SEG_D: U1.16 (TA1.0/P2.3), U3.10 (D), U4.10 (D), U5.10 (D), U6.10 (D)
/SEG_E: U1.17 (TA1.2/P2.4), U3.11 (E), U4.11 (E), U5.11 (E), U6.11 (E)
/SEG_F: U1.18 (TA1.2/P2.5), U3.3 (F), U4.3 (F), U5.3 (F), U6.3 (F)
/SEG_G: U1.27 (TA0.1/XIN/P2.6), U3.1 (G), U4.1 (G), U5.1 (G), U6.1 (G)
/SIMO: U1.23 (TDO/TDI/CAOUT/UCB0SIMO/UCB0SDA/A7/CA7/P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), U2.5 (MOSI)
/SOMI: U1.22 (TDI/TCLK/TA0.1/UCB0SOMI/UCB0SCL/A6/CA6/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), U2.2 (MISO)
/TEST: J2.TEST (Pin_17), U1.25 (SBWTCK/TEST)
/~CS: J1.P1.0 (Pin_2), U1.2 (TA0CLK/ACLK/A0/CA0/P1.0), U2.1 (~CS)
/~RST: J2.~RST (Pin_16), U1.24 (~RST~/NMI/SBWTDIO)
GND: C1.1, C2.2, J2.GND (Pin_20), RV1.1, SW1.1, U1.28 (DVSS), U2.4 (GND)
unnamed: J1.P1.1 (Pin_3), U1.3 (TA0.0/UCA0RXD/UCA0SOMI/A1/CA1/P1.1)
unnamed: J1.P1.2 (Pin_4), U1.4 (TA0.1/UCA0TXD/UCA0SIMO/A2/CA2/P1.2)
unnamed: J1.P1.3 (Pin_5), U1.5 (ADC10CLK/CAOUT/VREF-/VeREF-/A3/CA3/P1.3)
VCC: C1.2, C2.1, J1.3V3 (Pin_1), RV1.3, U1.1 (DVCC), U2.3 (~WP), U2.7 (~HOLD), U2.8 (VCC)

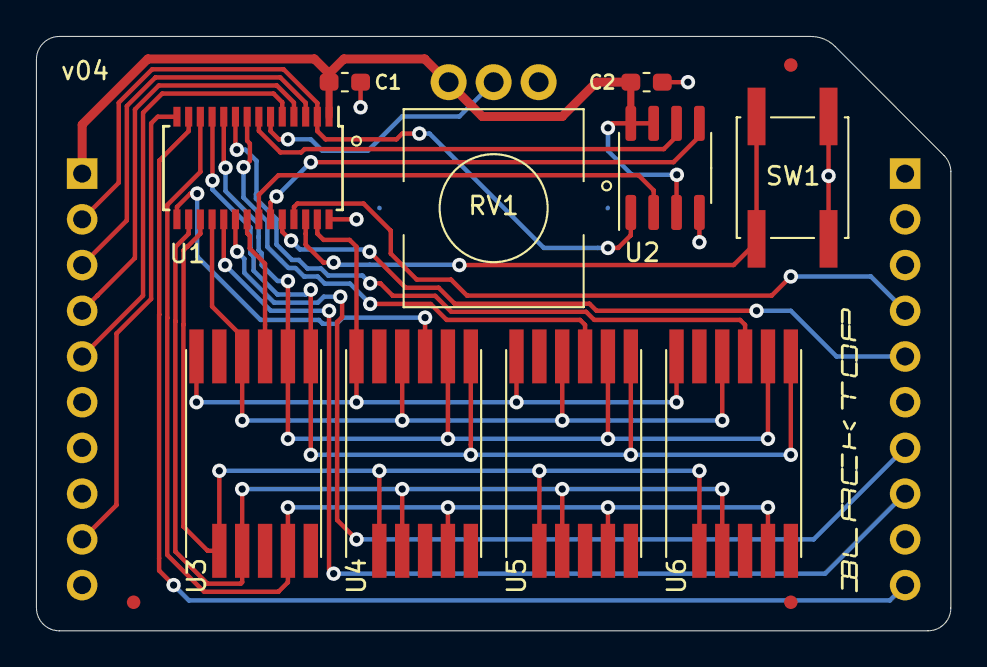
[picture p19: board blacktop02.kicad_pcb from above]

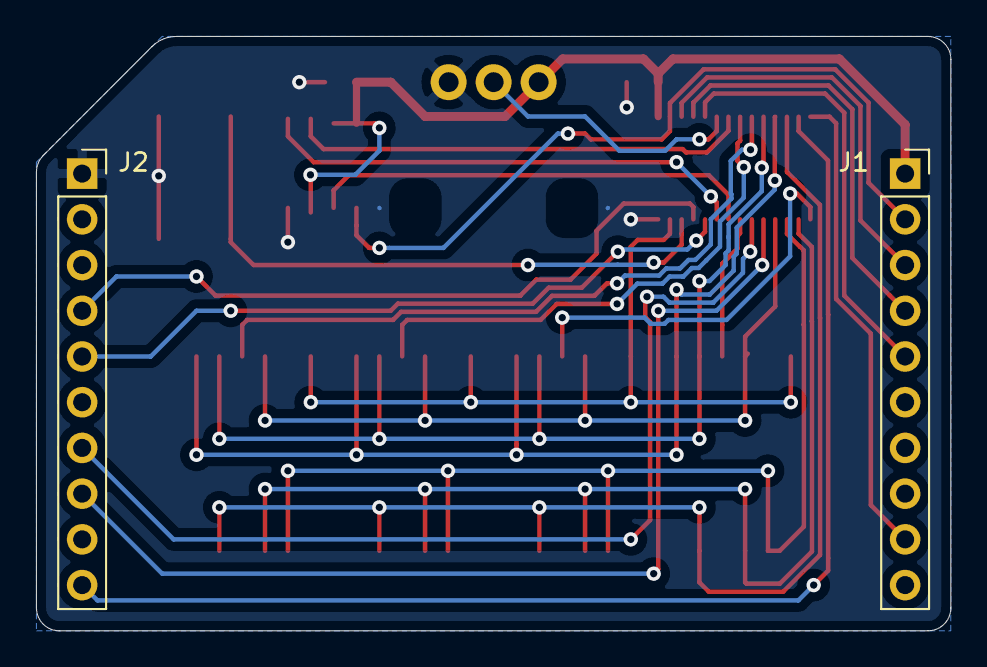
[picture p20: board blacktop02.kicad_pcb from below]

Board: 2 copper layers, 50.8 x 33.0 mm, 15 parts (2 on the bottom side), 28 nets.

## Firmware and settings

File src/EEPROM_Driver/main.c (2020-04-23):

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
#include <msp430.h>
#include <libemb/serial/serial.h>
#include <libemb/conio/conio.h>
#include <stdint.h>
#include <stdbool.h>

#include "eeprom.h"

void testReadAndWrite();
void testErase();
void testGroupReadAndPageWrite();

int main(void)
{
	WDTCTL  = WDTPW|WDTHOLD;
	BCSCTL1 = CALBC1_1MHZ;
	DCOCTL  = CALDCO_1MHZ;

	P3DIR |= (BIT2 | BIT3 | BIT5 | BIT6);
	P3OUT &= (~BIT2 & ~BIT3 & ~BIT5 & ~BIT6);
	
	eepromInit();
	
	testReadAndWrite();
	testErase();
	testGroupReadAndPageWrite();

	for(;;)
	{
	}
	return 0;
}

void testReadAndWrite()
{
	uint16_t address = 0x0000;
	uint8_t write_value = 0xcb;
	bool success = true;
	//write a value to all addresses and check, turn rgb green when successful

	while(address <= 0x1fff)
	{
		eepromWrite(address, write_value);
		address++;
	}

	address = 0x0000;

	while(address <= 0x1fff)
	{
		uint8_t read_value = 0xff;
		eepromRead(address, &read_value);
		if(read_value != write_value)
		{
			P3OUT |= BIT6;
			success = false;
			break;
		}
		address++;
	}
	if(success == true)
	{
		P3OUT |= BIT2;
	}
}

void testErase()
{
	bool success = true;
	//erase and check, turn rgb blue on when successful

	eepromErase();

	uint16_t address = 0x0000;

	while(address <= 0x1fff)
	{
		uint8_t read_value = 0xff;
		eepromRead(address, &read_value);
		if(read_value != 0x00)
		{
			P3OUT |= BIT6;
			success = false;
			break;
		}
		address++;
	}
	if(success == true)
	{
		P3OUT |= BIT5;
	}

}

void testGroupReadAndPageWrite()
{
	uint16_t address = 0x0000;
	bool success = true;
	//Test page write and block read, turn rgb white when successful
	uint8_t write_values[32] = {0x00};
	for(int i =0; i < 32; i++)
	{
		write_values[i] = i + 1;
	}

	eepromPageWrite(address, write_values, 32);

	uint8_t read_values[32] = {0x00};
	eepromBlockRead(address, read_values, 32);

	for(int i = 0; i <32; i++)
	{
		if(read_values[i] != write_values[i])
		{
			P3OUT |= BIT6;
			success = false;
			break;
		}
	}

	if(success == true)
	{
		P3OUT |= BIT3;
	}
}

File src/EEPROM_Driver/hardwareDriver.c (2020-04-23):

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
#include <msp430.h>
#include <libemb/serial/serial.h>
#include <libemb/conio/conio.h>
#include "eeprom.h"
#include "hardwareDriver.h"

/****************************
* Hardware Driver Functions *
*****************************/

void spiInit(void)
{
    //initialize MSP SPI
	P1OUT &= ~(BIT5 | BIT6 | BIT7);//set p1.5,1.6,1.7 to 0
	P1DIR |= (BIT5 | BIT6 | BIT7); //set p1.5,1.6,1.7 to outputs
	P1SEL |= BIT5 | BIT6 | BIT7; //configure pins
	P1SEL2 |= BIT5 | BIT6 | BIT7; //configure pins

	UCB0CTL1 |= UCSWRST; //put usci in reset mode to configure
	UCB0CTL1 |= UCSSEL_2; //SMCLK
	UCB0CTL0 = UCCKPH | UCMSB | UCMST | UCSYNC; //3-pin 8 bit spi master, most significant byte first, clock polarity high
	UCB0BR0 |=0x02;	//clock divider
	UCB0BR1 |=0;	//clock divider
	UCB0CTL1 &= ~UCSWRST; //remove the reset and SPI is ready to use
}

void csInit(void)
{
    //CS Line is default high
	P1DIR |= BIT0;
	P1OUT &= ~BIT0;
	__delay_cycles(8);
	P1OUT |= BIT0;
}

uint8_t readSPIBuffer(void)
{
    //Read the data from the slave
	uint8_t value = UCB0RXBUF;
    return value;
}

void repeatedEEPROMRead(uint8_t* message, uint8_t* data, int length)
{
    //set CS line low
	P1OUT &=~ BIT0;
	//send message bytes
	for(int i = 0; i < 3; i++)
	{
		UCB0TXBUF = message[i];
	}
	//Send read bytes
	for(int i = 0; i < length; i++)
	{
		UCB0TXBUF = 0x00; //dummy byte to allow reading
		//Read the data from the slave
		__delay_cycles(8);
		data[i] = UCB0RXBUF;
	}
	//reset CS line to high
	P1OUT |= BIT0;
}

void eepromWriteEnable(void)
{
	uint8_t message[2] = {0};
	message[0] = WREN;
	eepromSendMessage(message, 1);
}

void eepromWriteDisable(void)
{
	uint8_t message[2] = {0};
	message[0] = WRDI;
	eepromSendMessage(message, 1);
}

uint8_t eepromReadStatus(void)
{
	uint8_t message[2] = {0};
	message[0] = RDSR;
	message[1] = 0x00;
	eepromSendMessage(message, 2);
	uint8_t status = UCB0RXBUF;
	return status;
}

void eepromWriteStatus(uint8_t value)
{
	uint8_t message[2] = {0};
	message[0] = WRSR; 
	message[1] = value;
	eepromSendMessage(message, 2);
	__delay_cycles(8);
}

void eepromSendMessage(uint8_t* message, int length)
{
	//set CS line low
	P1OUT &=~ BIT0;

	for(int i = 0; i < length; i++)
	{
		UCB0TXBUF = message[i];
	}

	//reset CS line to high
	P1OUT |= BIT0;

	//delay
	__delay_cycles(8);
}

void eepromWaitForWriteCompletion(void)
{
	//wait until the status register indicates the write is complete
	uint8_t status = 0x01;
	do{
		status = eepromReadStatus();
	}while( (status & 0x01) == 0x01 ); //bit 1 of status register indicates write is in progress
}

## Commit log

2019-10-10 Added a file discussing resources for SPI
2020-02-06 version 01 of the pcb, ordered 2020-01-27
    [16seg_logo.dxf, blacktop01.kicad_pcb, blacktop01.sch]
2020-02-06 version 2, ordered 2020-01-30
    [16seg_logo.dxf, 16seg_logo_noseg.dxf, 16seg_logo_nox.dxf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]
2020-02-15 Added the load test files needed to flash board
2020-02-15 Made changes so that the red and green leds on the pcb are on
2020-02-15 Created a test program to test the new board
2020-02-15 v03 RC1 (rename is nontrivial so use v02 dir)
    [blacktop02.kicad_pcb, blacktop02.sch]
2020-02-17 moved RV1 pin3 from pin2 to GND
    [blacktop02.kicad_pcb, blacktop02.sch]
2020-02-17 v03 final, prototypes ordered 2020-02-17
    [blacktop02.kicad_pcb]
2020-02-20 Made changes for PCB 7segs
2020-03-23 a textfile with a linke to the youtube video of the finished board running was added to spikes
2020-03-29 Finished read function and got SPI driver working
2020-04-05 Overhauled the EEPROM SPI driver
2020-04-18 Tied eeprom 3 and 7 to VCC, board v04 RC
    [blacktop02.sch, noname.kicad_pcb]
2020-04-20 Added PDF of v04 schematic
2020-04-24 Added test jig cad and BOM
    [#MSP-EXP430G2ET-1.dxf, #MSP-EXP430G2ET-2.dxf, ArduinoMega.SLDPRT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]

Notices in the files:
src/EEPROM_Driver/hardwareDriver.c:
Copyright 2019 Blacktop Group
